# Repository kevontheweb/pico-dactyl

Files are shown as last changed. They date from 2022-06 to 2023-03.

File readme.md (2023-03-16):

# PicoDactyl

> **THIS HAS BEEN ARCHIVED**
> I am leaving this here because it has a pretty decent readme with the thought process for desighning a handware that I will probably want to come back to.
> I printed half the dactyl and then realised i do not like how it feels.

inspiration:

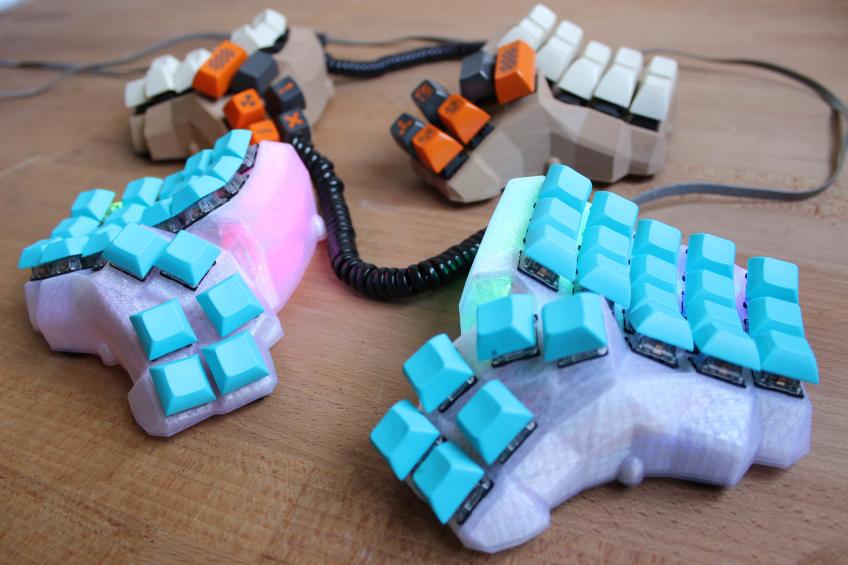
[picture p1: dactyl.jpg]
inpiration


## hardware

The following are links to purchase hardware at [microrobotics.org.za](https://microrobotics.org.za).
If you are not located in South Africa you should use your own local electronics store.

- [rpi pico](https://www.robotics.org.za/PI-PICO)
  - [datasheet](https://datasheets.raspberrypi.com/pico/pico-datasheet.pdf)
- [pcf8575](https://www.robotics.org.za/PCF8575-MOD)
  - [python library](https://pypi.org/project/pcf8575/)
  - [datasheet](https://www.ti.com/product/PCF8575)
  - [check this example firmware](https://github.com/KMKfw/kmk_firmware/blob/74fa1fb52e41b95c1df9047e1ffff39001bb67e6/user_keymaps/dzervas/lab68.py) which uses a different i2c expander chip
    - [mcp23017 io expander](https://www.robotics.org.za/MCP23017-DIPo) (out of stock at time of planning)
      - [datasheet](https://ww1.microchip.com/downloads/en/devicedoc/20001952c.pdf)
      - [example circuit](https://www.best-microcontroller-projects.com/mcp23017.html)
      - [another example schematic](https://cdn-learn.adafruit.com/assets/assets/000/036/490/original/lcds___displays_schem.png?1476373463)
- [rj 45 connectors](https://www.robotics.org.za/RJ45-CON-PCB)
  - provides up to eight wires
- [usb B printer cable](https://www.robotics.org.za/PAN-USBB-MUSB)
- [EC11 rotary encoder](https://www.robotics.org.za/EC11-VER-20)
- [M3 brass heat set inserts](https://www.robotics.org.za/SUL-M3-20)
- cherry mx brown switches (salvaged from another keyboard)

## design

- minidox/corne/reviung inspired design
  - 3x6 for main clusters
  - 3/4 keys per hand for thumb cluster
    - can therefore use 2 3x7 matrices and use the rj45 connector for scl/sda/vbus/gnd/v+
  - rotary encoder on one half
  - rgb leds (ws2812 rings from banggood)
    - need 1 data pin (din), power and ground (**check pico datasheet for whether to use vbus or vdd!**)
  - printed in transparent (translucent) PLA
    - print time is estimated 18 hours per side (excluding bottom plate)
  - will need to design inserts for the rj45 connectors and for the usb B adaptor as well as the pi pico holder
    - loligag sled format
      - [example](https://www.printables.com/model/152130-dactyl-maniform-pro-micro-v2-type-c-sled)
    - [wally plate gen](https://www.thingiverse.com/thing:47956/files)
  - will also need to design holder for led rings (probably on the base plate)
  - holder for the pi pico and the io expander
    - [this on from printables.com](https://www.printables.com/model/106736-raspberry-pi-pico-spacer-standoff)
  - use [this converter](https://www.thingiverse.com/thing:3770166) to mount an ec11 encoder in an mx socket.

I used [this dactyl case generator](https://github.com/joshreve/dactyl-keyboard) that uses open cascade and generates much neater models (cleaner stls).

- see ``run_config.json`` for my config used to generate the case
- installation was fairly simple:
  1. install docker desktop
  2. download the dactyl case generator repo
  3. run the ``build_docker.bat`` script.
  4. in docker desktop open the DM-shell container in terminal and run ``bash``
  5. run ``generate_configuration.py``
  6. edit ``src/run_config.json`` (don't forget to save)
  7. run ``python3 dactyl_manuform.py``
  8. open ``things/DM_left.scad`` and preview it in openSCAD
  9. repeat steps 6-8 until happy with the case.
  10. compile the case files in openSCAD and export the stls

my tweaks were:

- 3x6 design with 3 keys on each thumb cluster
- remove oled clips (use ``null``)
- make screw posts larger to fit my inserts
- import into tinkercad to make holes for the connectors and attach mounts for the controller boards
- cleanup mesh in blender (some of the screw posts were sticking through the outside of the case).

### **edit**: Custom case?

I am currently working on a custom dactylesqu case inspired by the skeletyl. I want to try to close all the gaps without making it look spikey.
Doing it from scratch will also make the connectors a bit more polished than my attempts at hacking together stls in tinkercad.
I am using onShape for the time being and it is my first time actually using a real cad package so this might take a while.

custom curvy case

## firmware

IO expander:

- [some example firmware using an IO expander](https://github.com/KMKfw/kmk_firmware/blob/74fa1fb52e41b95c1df9047e1ffff39001bb67e6/user_keymaps/dzervas/lab68.py)
- [more example firmware with pcf8575 ](https://github.com/kevin-nel/PyOledukey/blob/master/CircuitPython/kb.py)(commented out)
- [adafruit pcf8575 example](https://learn.adafruit.com/adafruit-pcf8575/overview)
- [adafruit circuit python module for the pcf8575](https://github.com/adafruit/Adafruit_CircuitPython_MCP230xx)

Pi Pico

- mostly just going to try [KMK](https://github.com/KMKfw/kmk_firmware) there are lots of examples

## construction

- do columns/rows and diodes first
- attach connectors and micros
- measure out the length of wire to connect rows and columns
- connect rows/cols to the micros and connectors
- hotglue any switches/components that are not fitting tightly

circuit diagram:
circuit

## references

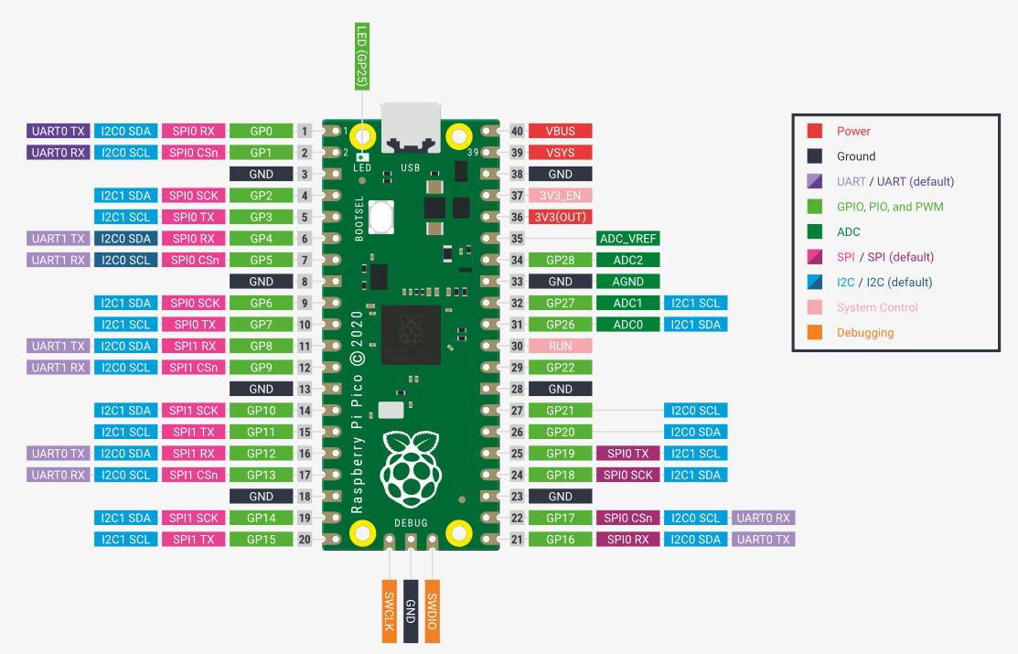
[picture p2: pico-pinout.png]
pico pinout

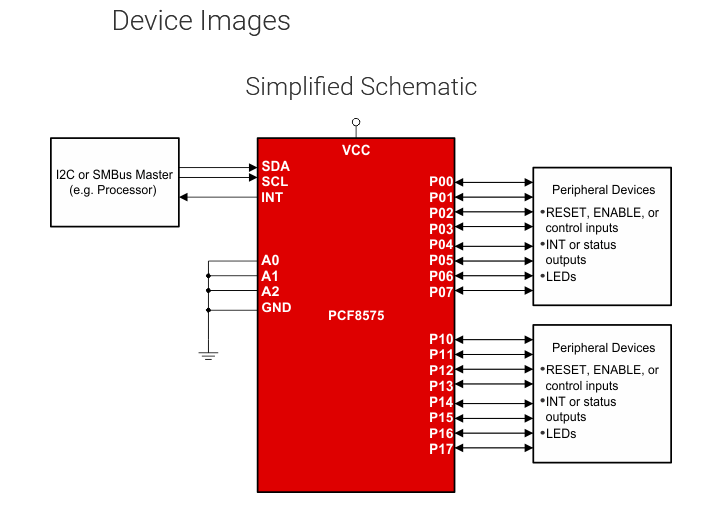
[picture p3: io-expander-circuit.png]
io expander pinout


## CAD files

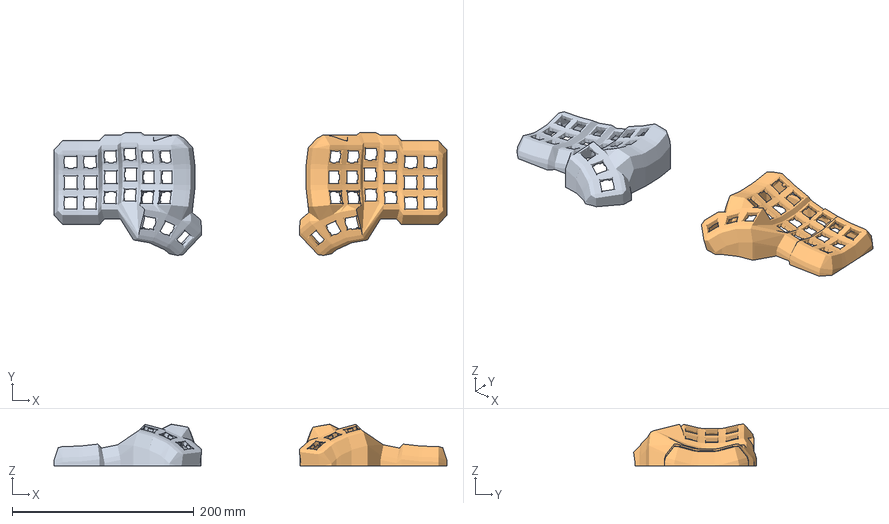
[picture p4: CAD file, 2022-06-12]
things/case/print.3mf
432.6 x 135.2 x 45.9 mm
DM-left.stl
DM-right.stl

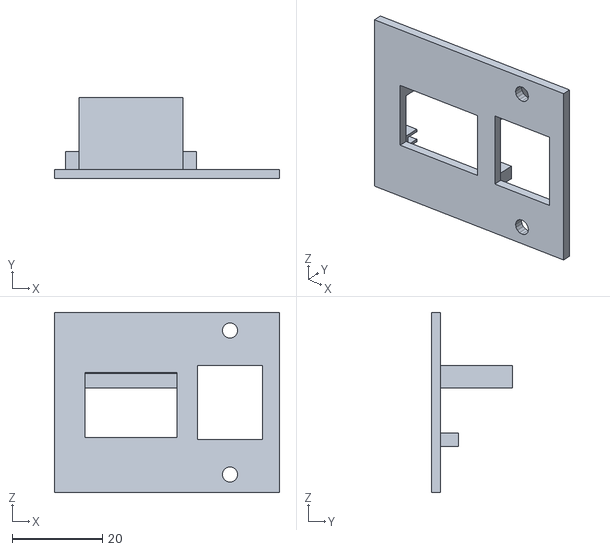
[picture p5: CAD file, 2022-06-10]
things/connectors/custom_loligagger_holster.stl
50.0 x 18.0 x 40.0

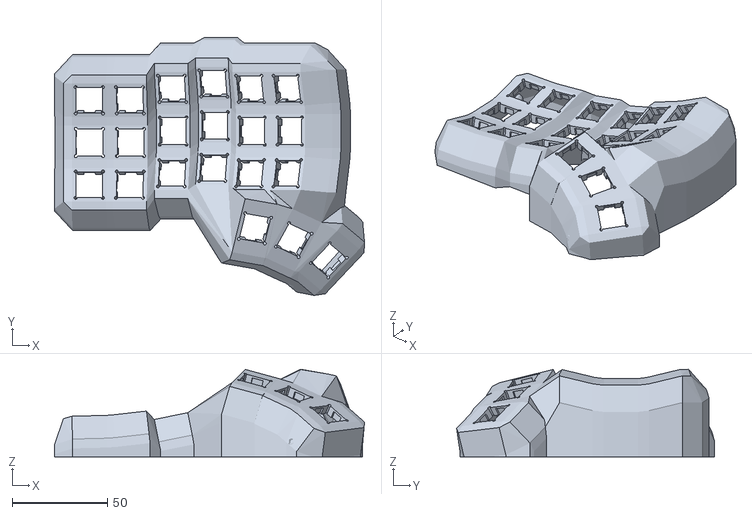
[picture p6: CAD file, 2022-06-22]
things/plate/DM_left_blank.stl
162.6 x 135.2 x 45.9

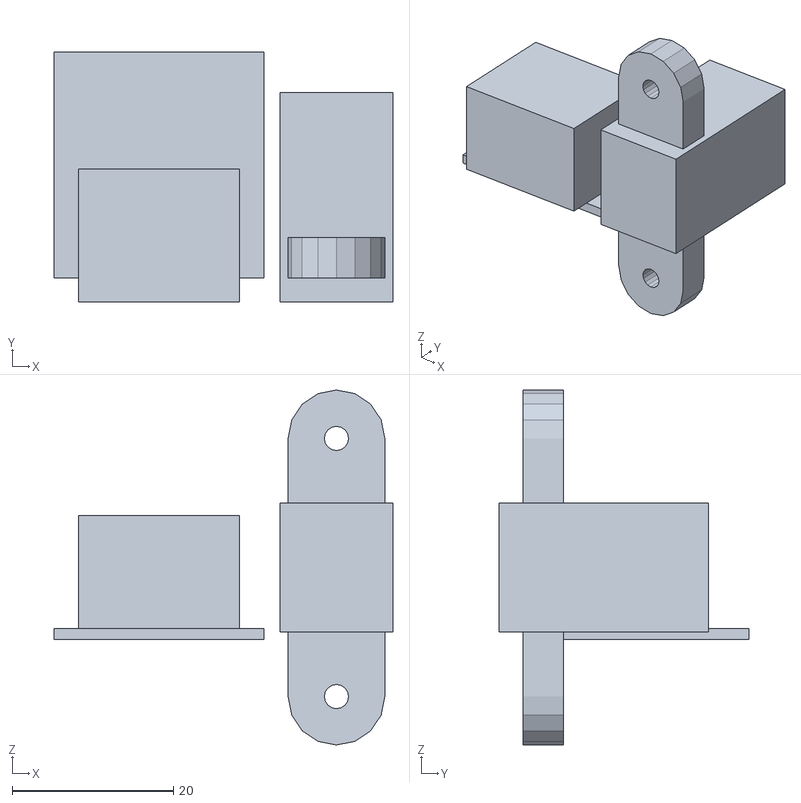
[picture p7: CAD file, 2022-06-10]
things/connectors/connectors.stl
42.0 x 31.0 x 44.0

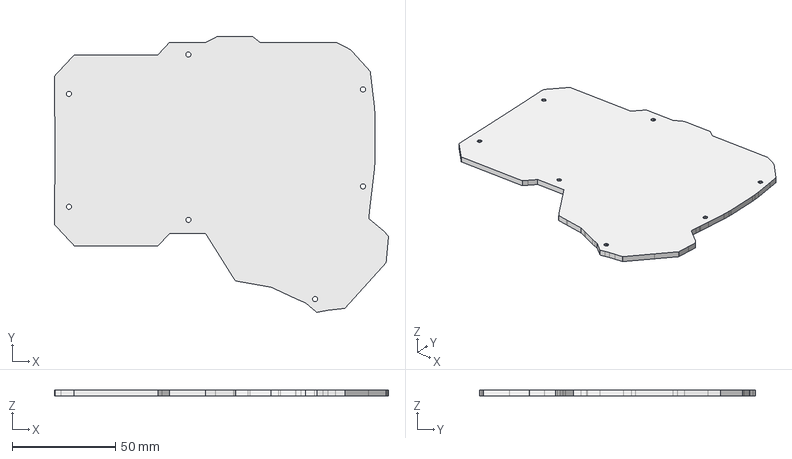
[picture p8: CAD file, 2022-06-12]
things/plate/DM_plate.FCStd
161.6 x 133.5 x 3.00 mm

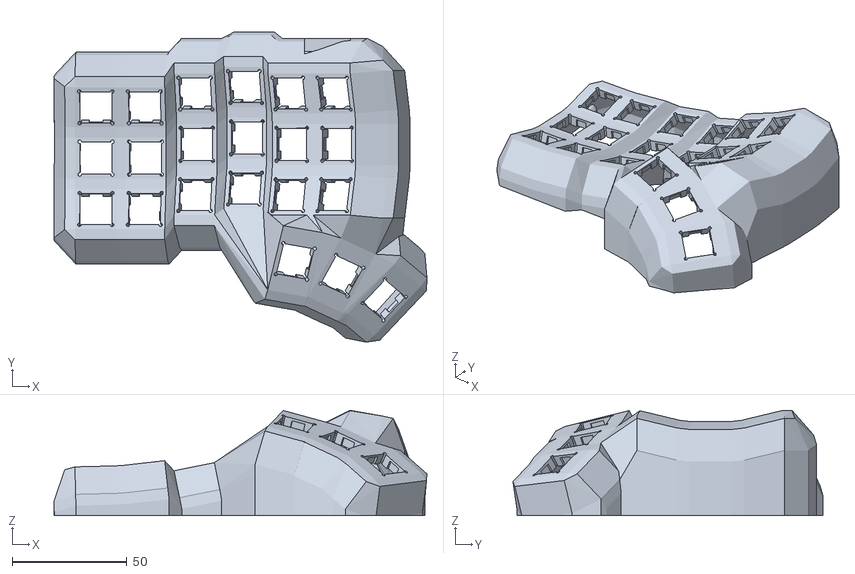
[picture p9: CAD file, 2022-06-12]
things/case/DM-left.stl
162.6 x 135.2 x 45.9

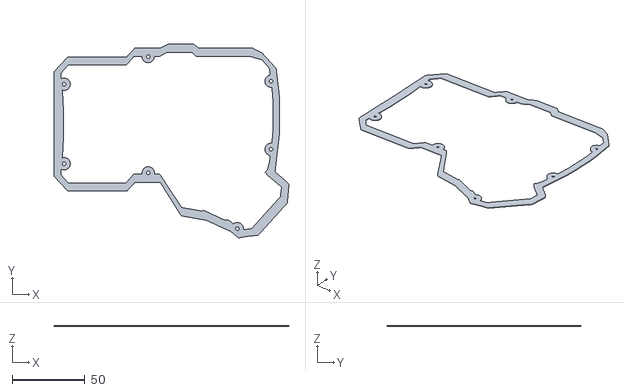
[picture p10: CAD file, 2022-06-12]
things/plate/make-plate-src.stl
161.6 x 133.5 x 1.00

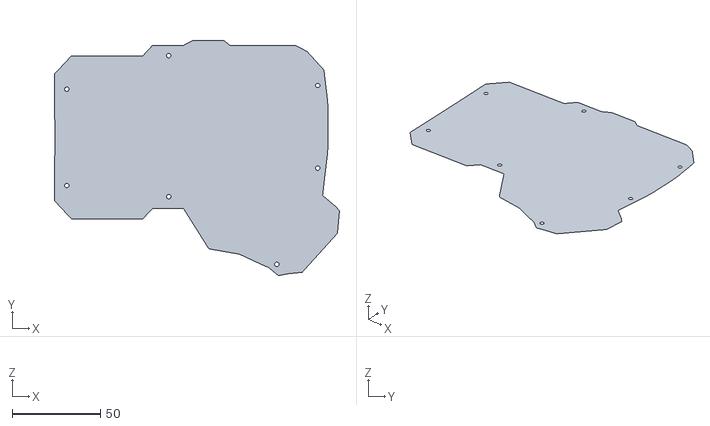
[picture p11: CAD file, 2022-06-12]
things/plate/make-plate-cut.stl
161.6 x 133.5 x 0

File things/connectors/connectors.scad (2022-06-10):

tolerance=0.4;
//loligagger mount
/*
translate([0,0,-12.5/2])union(){
cube([28.75,4.55,12.5], center=true);
translate([0,((4.55-2)/2 - 4.55),-4/2])cube([36.75,2,16.5],center=true);
}
*/


//usb b
translate([14,0,0])rotate([0,180,0])union(){
    rotate([0,90,0])union(){
        translate([0,26/2-3,0])cube([16,26,14],center=true);

        difference(){
            hull(){
                translate([16,5,0])rotate([90])cylinder(d=12, h=5, $fn=16);
                translate([-16,5,0])rotate([90])cylinder(d=12, h=5, $fn=16);
            }
            union(){
                translate([16,10,0])rotate([90])cylinder(d=3, h=20, $fn=16);
                translate([-16,10,0])rotate([90])cylinder(d=3, h=20, $fn=16);
            }
        }
    }

//rj45
    translate([22,28/2,16.5/2])union(){
        translate([0,-28/2+16.5/2-3, - 14/2 - 1.4/2])cube([20,16.5,14], center=true);
        cube([26, 28, 1.4], center=true);
    }
}




/*
union(){
    difference(){
        //plate
        translate([0,-2,0])cube([50,2,40],center=true);

        //holes
        translate([14,0,0])rotate([0,180,0])union(){
            rotate([0,90,0])union(){
                translate([16,10,0])rotate([90])cylinder(d=3+tolerance, h=20, $fn=16);
                translate([-16,10,0])rotate([90])cylinder(d=3+tolerance, h=20, $fn=16);
            }

            rotate([0,180,0])union(){
                rotate([0,90,0])union(){
                    translate([0,26/2-3-1,0])cube([16+tolerance,26,14+tolerance],center=true);
                }
            }

            translate([22,28/2,16.5/2])union(){
                translate([0,-28/2+16.5/2-3-1, - 14/2 - 1.4/2])cube([20+tolerance,16.5,14+tolerance], center=true);
            }
        }
    }
    //clips
    translate([14,0,0])rotate([0,180,0])translate([22,28/2,16.5/2])union(){
        difference(){
            union(){
                translate([22/2+3/2,-28/2+1,0])cube([4,4,3],center=true);
                translate([-22/2-3/2,-28/2+1,0])cube([4,4,3],center=true);
            }
            cube([26+tolerance, 28, 1.4+tolerance], center=true);
        }
        difference(){
            translate([0,-16.5/2+1,-14])cube([20+3,16.5,5],center=true);
            translate([0,-28/2+16.5/2-3, - 14/2 - 1.4/2])cube([20+tolerance,16.5+tolerance,14], center=true);
        }
    }
}
*/

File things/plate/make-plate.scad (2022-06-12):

projection(cut=false)
   translate([0,0,0])import("make-plate-src.stl");

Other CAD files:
things/case/DM-right.stl

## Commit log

2022-06-06 update to use pcf8575 instead of mcp io expander (out of stock)
    also improve circuit diagram
2022-06-10 update to use the openCASCADE dactyl generator by joshreve
    [DM_left.stl, DM_right.stl, EC11_to_MX_Adapter_V2.stl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]
2022-06-10 v1 with holes for connectors and mounts for controller boards
    need to test print the board mounts and make a clip for the rj45 connector still
    [DM_left_no_holder.stl, DM_left_with_holes_v1.stl, DM_right_no_holder.stl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]
2022-06-12 fix things
    [DM_left_no_holder.stl, DM_left_no_holder_bigger_holes.stl, DM_plate.FCStd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]
2022-06-12 cleanup files
    [DM-left.stl, DM-right.stl, DM_left.stl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]
